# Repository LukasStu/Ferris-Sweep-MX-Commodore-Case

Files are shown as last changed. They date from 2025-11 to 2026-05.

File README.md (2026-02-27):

# Ferris Sweep MX Commodore Case

Custom gasket-mount style case for the Ferris Sweep Bling MX.

## Table of Contents

- [Overview](#overview)
- [Gallery](#gallery)
- [What Changed in v2](#what-changed-in-v2)
- [Repository Structure](#repository-structure)
- [Quick Start](#quick-start)
  - [PART Output Matrix](#part-output-matrix)
- [Architecture Overview](#architecture-overview)
  - [DXF Layer Contract](#dxf-layer-contract)
- [Bill of Materials (BOM)](#bill-of-materials-bom)
- [Print Guidance](#print-guidance)
- [Key Parameters](#key-parameters)
  - [USB Outlet Alignment](#usb-outlet-alignment)
  - [pcb_usb_distance](#pcb_usb_distance)
  - [controller_cover_thickness (optional)](#controller_cover_thickness-optional)
  - [Gasket Setup](#gasket-setup)
  - [Heat Inserts and Screws](#heat-inserts-and-screws)
  - [USB Outlet Cover Retention](#usb-outlet-cover-retention)
- [Acoustics](#acoustics)
- [CI / Automation](#ci--automation)
- [License](#license)

## Overview

The design was inspired by a Reddit post that showed a gasket mount style case for the Ferris Sweep Bling MX. No STL files were published, so this repository contains my own implementation.

Primary focus:

- Protection with an enclosed case
- Access to power switch, reset button, and USB port
- Gasket mount style isolation
- Improved typing acoustics

## Gallery

| | |
|---|---|
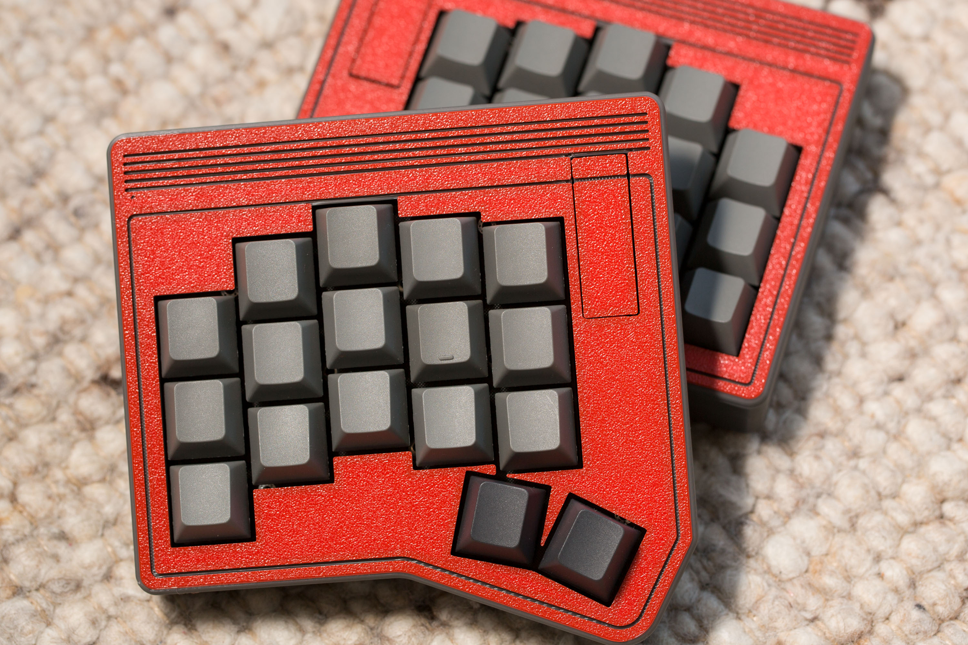
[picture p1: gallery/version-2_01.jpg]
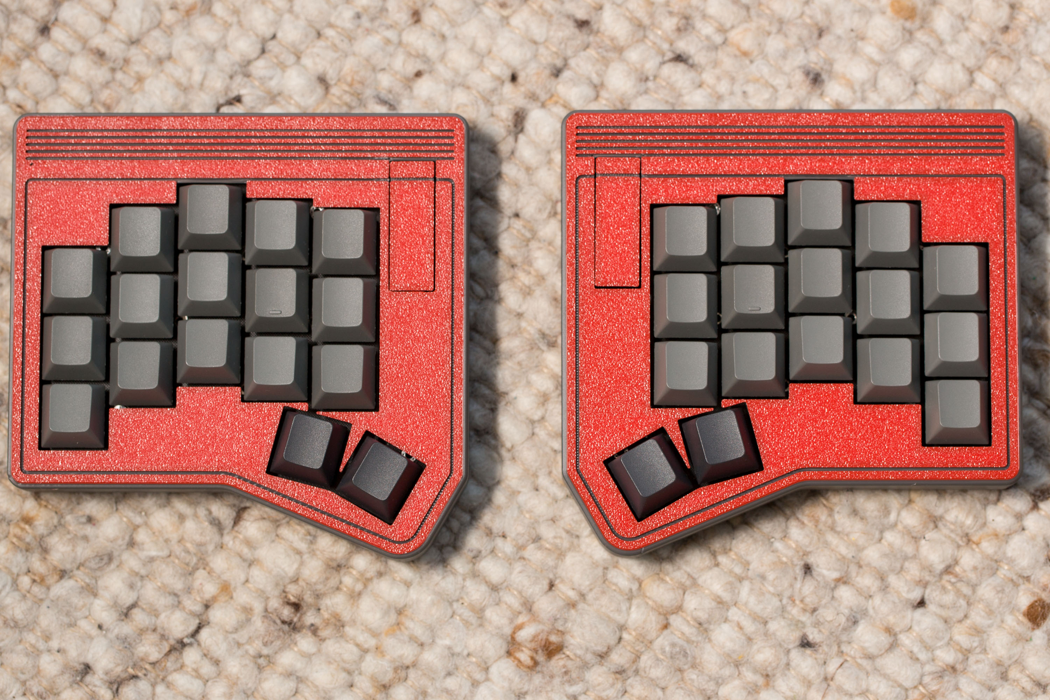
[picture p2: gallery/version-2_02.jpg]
|  |   |
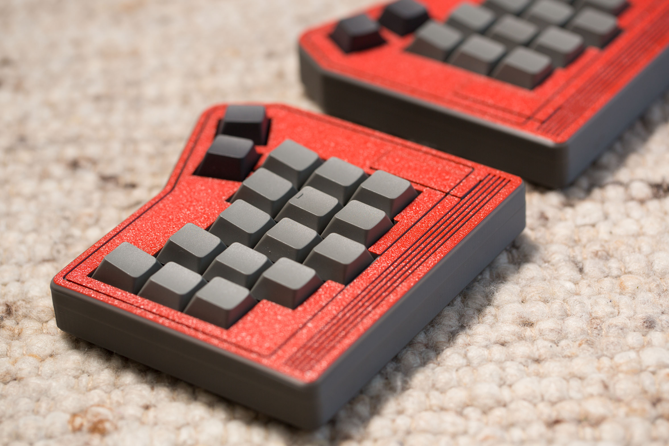
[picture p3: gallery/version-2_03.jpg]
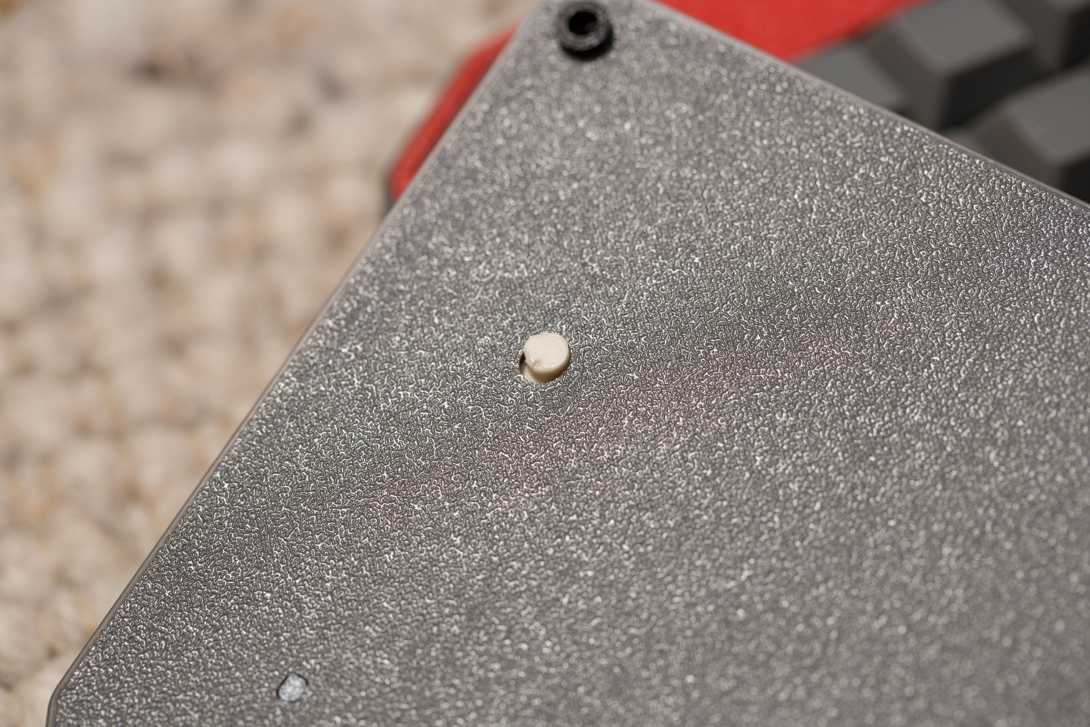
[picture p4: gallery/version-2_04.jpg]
|   |   |
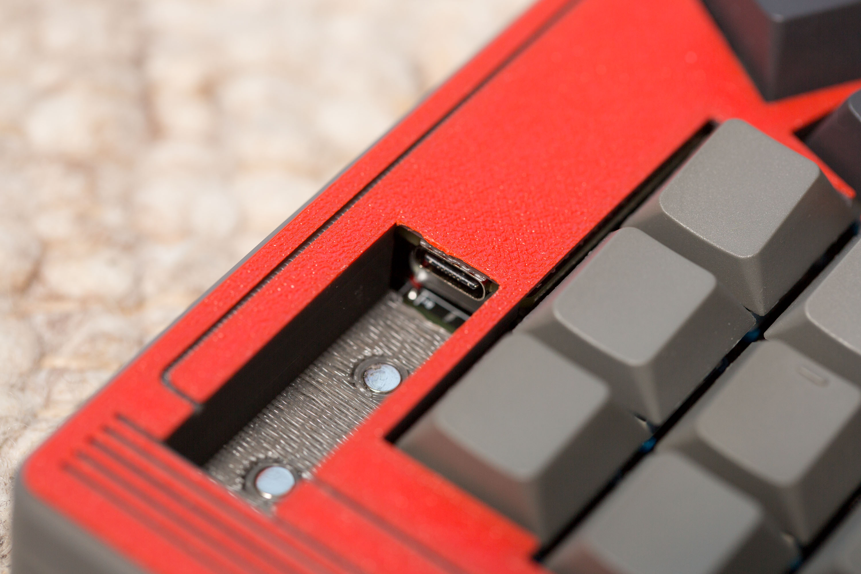
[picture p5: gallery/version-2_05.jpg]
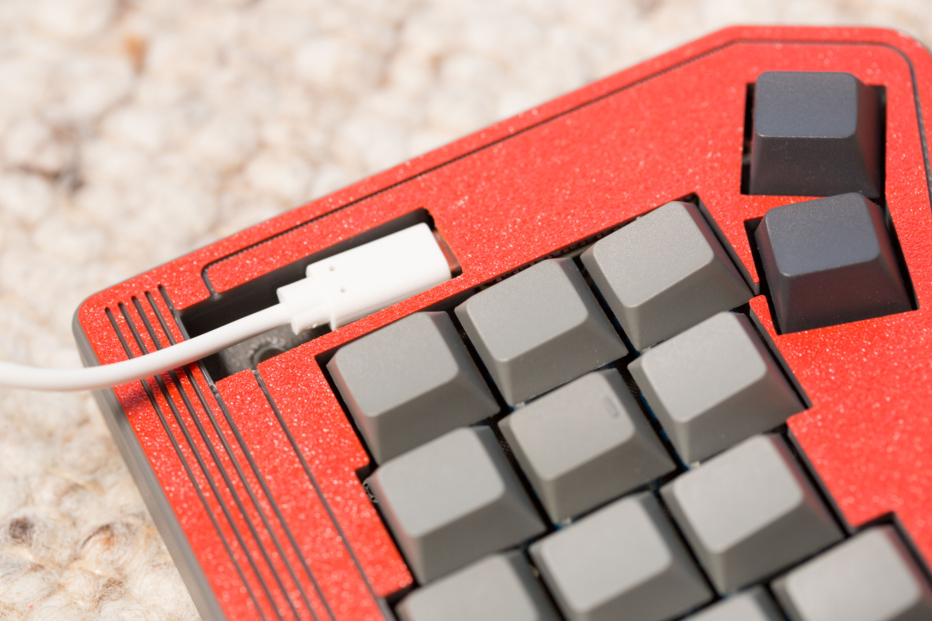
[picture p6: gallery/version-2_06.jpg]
|   |   |
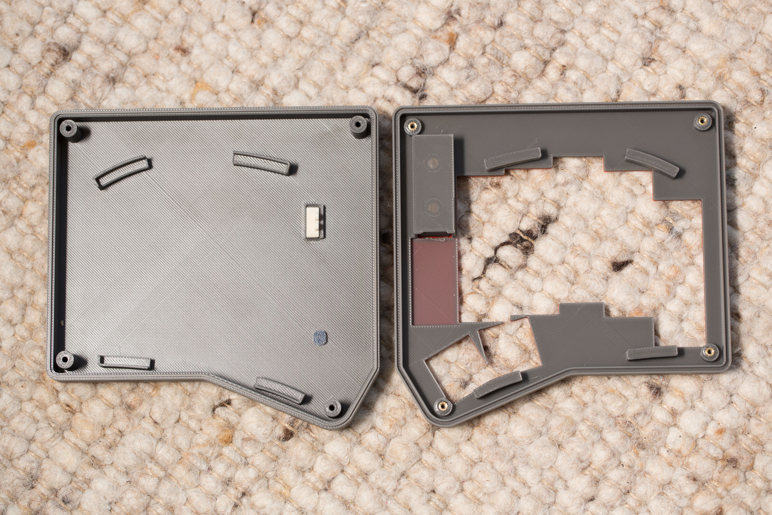
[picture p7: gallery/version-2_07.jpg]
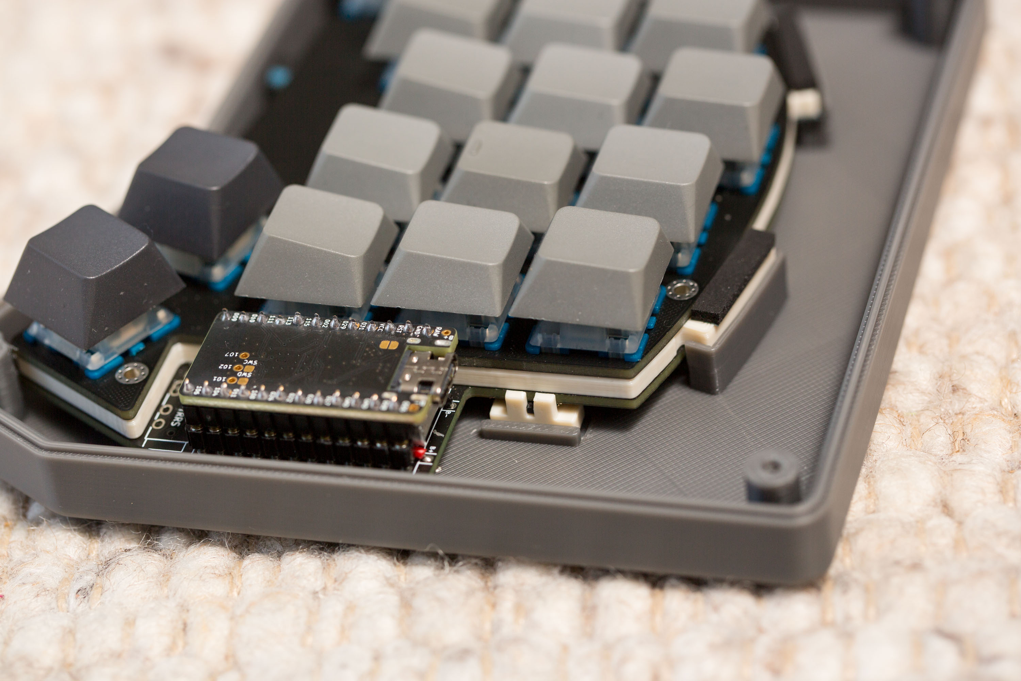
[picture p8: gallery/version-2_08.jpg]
|   |   |

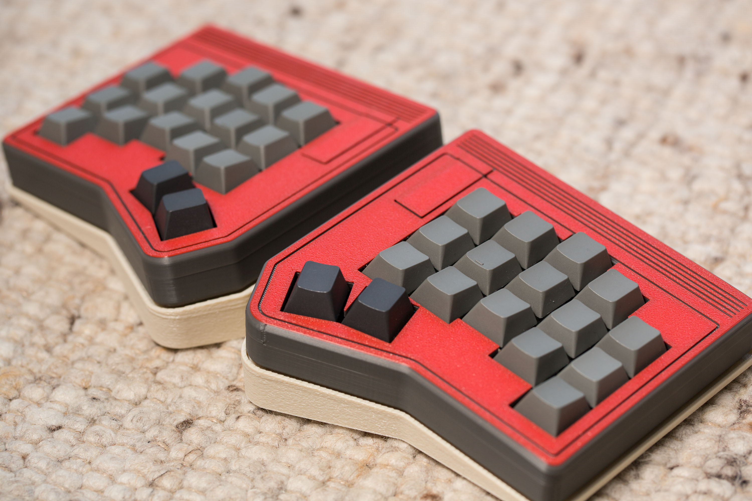
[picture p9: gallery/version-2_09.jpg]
|   | 

## What Changed in v2

- Introduced gasket mount style
- Improved structural rigidity
- Better acoustic behavior

## Repository Structure

- `case/case.scad`: Main OpenSCAD generator
- `case/ferris_sweep_bling_mx.dxf`: Source 2D layers used for all major extrusions
- `gallery/`: Build and fit photos

## Quick Start

1. Open `case/case.scad` in OpenSCAD.
2. Set `PART` to the part you want to export (`top_case`, `bottom_case`, `switch_plate_foam`, etc.).
3. Render with `F6`.
4. Export STL.

Use `PART = "exploded"` to inspect clearances and stack order before final export. You can also set `EXPLODE = 0` to inspect the assembled geometry while still using exploded build logic.

### PART Output Matrix

| `PART` value | STL export | Required for build | Purpose |
|---|---|---|---|
| `top_case` | `top_case.stl` | Yes | Top shell with keycap and controller cutouts |
| `bottom_case` | `bottom_case.stl` | Yes | Bottom shell with supports and screw structures |
| `switch_plate_foam` | `switch_plate_foam.stl` | Yes | Plate/foam interface layer |
| `power_switch_slider` | `power_switch_slider.stl` | Yes | External power slider part |
| `reset_switch_button` | `reset_switch_button.stl` | Yes | External reset button part |
| `usb_plug_cover` | `usb_plug_cover.stl` | Optional | Removable USB outlet cover |
| `rubber_feet` | `rubber_feet.stl` | Optional | Optional printed feet inserts |
| `tent` | `tent.stl` | Optional | Optional tenting support |
| `exploded` | *(view only)* | No | Visual assembly / clearance inspection |

## Architecture Overview

The OpenSCAD code in `case/case.scad` follows a lightweight modular structure:

- `extrude_layer(layer, z, h, delta)` is the primary helper. It imports a DXF layer and extrudes it with optional offset.
- Higher-level modules such as `top_case`, `bottom_case`, and accessories build geometry through boolean operations around shared extrusions.
- `build()` is the entry point. It reads `PART` and renders the selected component.

This separation makes it easy to tune parameters, update DXF layers, or add modules without changing core helper routines.

### DXF Layer Contract

The following DXF layers are expected by `case/case.scad`. Renaming or removing layers will break matching modules.

| Layer name | Purpose |
|---|---|
| `pcb_outline` | PCB and internal clearance envelope |
| `outer_shape` | Main outside perimeter |
| `outer_shape_decor` | Top decorative area cutout |
| `decor_lines` | Decorative line engraving/cutout |
| `keycaps_outline` | Keycap clearance opening |
| `controller_cutout` | Controller/USB area opening |
| `reset` | Reset button geometry |
| `pwr_lid_cutout` | Power slider top cutout |
| `pwr_body` | Power slider body |
| `pwr_circ` | Power slider cap/circle |
| `pwr_body_support` | Internal support under power area |
| `pwr_knob_cutout` | Slider knob relief |
| `pwr_body_overhang` | Slider overhang guidance |
| `pwr_overhang_cutout` | Overhang clearance cutout |
| `pwr_on_label` | Optional ON marking |
| `switches` | Switch opening references |
| `switchplate_outline` | Switchplate foam outline |
| `gasket_supports` | Gasket support contact areas |
| `gasket_supports_rim` | Gasket rim geometry |
| `screw_markers` | Screw/insert marker positions |
| `usb_plug_cutout` | USB cover body cutout |
| `usb_plug_decor` | Optional USB cover decorative cutout |
| `usb_plug_magnets` | USB cover magnet pockets |

## Bill of Materials (BOM)

Quantity notation:

- **Per half** = one keyboard half
- **Total pair** = full split keyboard (two halves)

| Item | Spec used | Per half | Total pair |
|---|---|---|---|
| Heat-set inserts | M2 x 3 x 3.5 | same as screw marker count | 2x per-half count |
| Screws | M2 hex, 4 mm length | same as screw marker count | 2x per-half count |
| USB cover magnets | 4 mm x 1 mm | 2 | 4 |
| Gasket strips | Poron, 2 mm | as required by gasket path | 2x per-half amount |

Notes:

- Heat-set inserts are required for this design.
- Tested insert install temperature in PETG: **190°C**.
- If you use different inserts or screws, adjust the matching parameters in `case/case.scad`.

## Print Guidance

Baseline used for successful builds:

- Material: PETG
- Infill: 40% gyroid
- Supports used: screw hole support areas and the USB cutout region

Recommended starting approach:

- Print each `PART` in its natural flat orientation from OpenSCAD export.
- Supports were used specifically at screw hole support areas and the USB cutout; keep supports targeted to those regions.
- Keep wall/perimeter settings consistent across top and bottom shells for even seam behavior.

## Key Parameters

### USB Outlet Alignment

The position of the USB-C port depends on your solder-pin configuration and controller setup.

#### `pcb_usb_distance`

- Definition: Distance (mm) from PCB surface to USB-C port center
- Purpose: Aligns the USB opening with your connector

<p align="center">
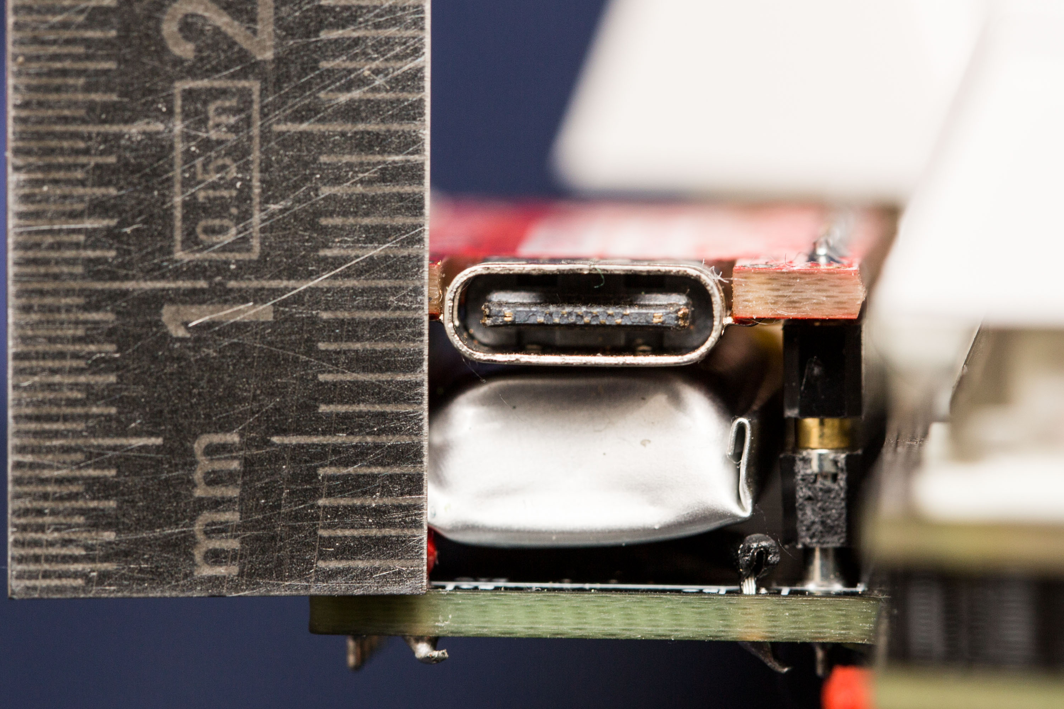
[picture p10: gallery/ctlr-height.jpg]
Measuring PCB to USB-C port center distance
  <br>
  <em>Caption: Measuring PCB-to-USB-C center distance (example value: 9 mm)</em>
</p>

#### `controller_cover_thickness` (optional)

- Definition: Wall thickness above the controller area near the USB outlet
- Default: `1` mm
- Adjustment: Increase if your controller sits deeper or if that wall is too thin

Adjust in `case.scad`:

```scad
pcb_usb_distance = <your measured value>;          // e.g. 9
controller_cover_thickness = <desired thickness>;  // e.g. 1.5
```

Then render (`F6`) and verify alignment before exporting STLs.

### Gasket Setup

The case is designed for Poron gasket strips and uses a compression model.

- Material used: 2 mm Poron foam strips
- Target compression: 60%
- Configured by:

```scad
gasket_thickness = 2;
compression = 0.6;
compressed_gasket_thickness = gasket_thickness * (1 - compression);
```

Adjustable:

- `gasket_thickness`: Match your actual foam thickness
- `compression`: Tune feel and preload

Do not adjust:

- `switch_plate_foam_thickness` should remain fixed. It represents the physical distance between PCB and switch plate defined by the MX switch stack-up.

### Heat Inserts and Screws

Heat-set inserts are required and are installed in the **top shell**.

Reference hardware used for this build:

- Insert: **M2 x 3 x 3.5**
- Screw: **M2 hex, 4 mm thread length**
- Tested insert install temperature in PETG: **190°C**

Install guidance:

- Heat the insert tool, align the insert perpendicular to the hole, and press in slowly.
- Stop when the insert is flush with the pocket surface (avoid over-driving).
- Let the area cool fully before test-fitting screws.

If you use different inserts or screws, tune these parameters in `case/case.scad`:

- `heat_sink_insert_diameter`: Insert outer diameter fit
- `heat_sink_insert_depth`: Insert pocket depth
- `screw_diameter`: Clearance for screw threads
- `head_diameter`: Clearance for screw head
- `thread_length`: Effective screw engagement length
- `thread_intrusion`: How far screw threads extend into the structure
- `screw_support_diameter`: Diameter of local support around screw locations

### USB Outlet Cover Retention

The USB outlet cover is held in place with magnets.

- Magnet size: **4 mm x 1 mm**
- Quantity used: **2 magnets per case half**
- Mounting method used: **glued in place**

## Acoustics

This case is tuned for a muted, less hollow sound profile through gasket isolation and enclosure rigidity.

Baseline used:

- Infill: 40% gyroid
- Gasket: 2 mm Poron strips
- Compression target: 60%

Why this works:

- Gasket isolation reduces direct transfer of high-frequency vibration into the shell
- 40% gyroid infill improves structural consistency and lowers resonance versus low infill
- Enclosed geometry and wall thickness add mass and reduce hollowness

Tuning notes:

- If sound is too sharp: increase `compression` slightly or use softer gasket foam
- If feel is too soft/over-damped: reduce `compression` slightly
- Keep `switch_plate_foam_thickness` unchanged

## CI / Automation

- Build STLs on push: Renders all STL parts on push/PR/manual run and uploads a consolidated `case` artifact
- Build and Release STLs: Runs on tags (`v*`), builds all parts, bundles `case.zip`, and publishes a GitHub Release

## License

See `LICENSE`.

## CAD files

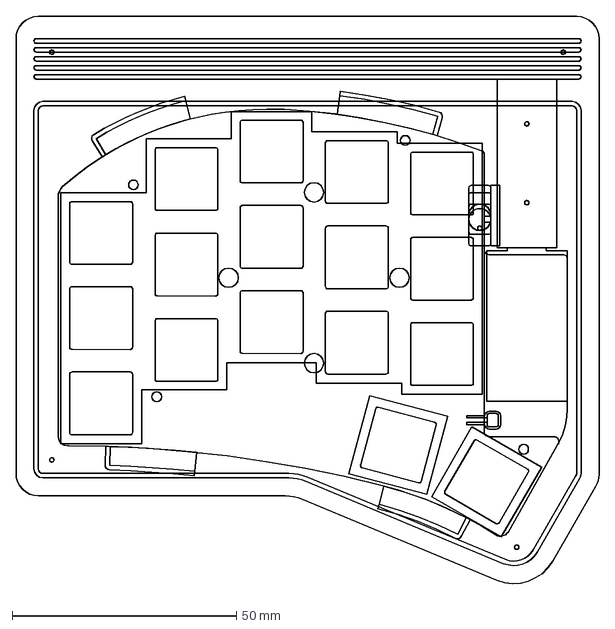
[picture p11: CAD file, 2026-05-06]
case/ferris_sweep_bling_mx.dxf
130.0 x 127.6 mm

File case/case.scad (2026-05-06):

// -----------------------------------------------------------------------------
// Ferris Sweep MX Case Generator
// Author: Lukas Stürmlinger
// Requires: OpenSCAD 2021+ and ferris_sweep_bling_mx.dxf in the same directory.
// Description: Builds top/bottom shells, switch-plate foam, slider, reset button,
//              and optional tent support by extruding DXF layers via extrude_layer().
// Usage: Set PART to "top_case", "bottom_case", etc., then F6 to render.
// Notes: All dimensions in millimeters; DXF layers listed below must be kept in sync.
// CI: Every push triggers .github/workflows/build-stls-on-push.yml to render all STLs via GitHub Actions.
// -----------------------------------------------------------------------------
$fn = 100;

// Dimensions & geometry
// -------------------- Parameters --------------------
// top case
fillet_radius = 2.5;
top_case_thickness = 3;
case_wall_thickness = 3;
controller_cover_thickness = 1;
keycaps_gap = 0.5;
keycaps_cutout_height = 8.5;
decoration_cutout_depth = 1.0;

// bottom case
bottom_thickness = 2;
bottom_gap = 1.5;

// rim
rim = 1;
rim_height = 1;
rim_clear = 0.2;

// PCB + plate
kailh_sockets_thickness = 2;
fr4_thickness = 1.6;
switch_plate_foam_thickness = 3.3;

// gasket
gasket_thickness = 2;
compression = 0.5;
compressed_gasket_thickness = gasket_thickness * (1 - compression);
gasket_rim = 1.5;

// switches
switch_protrusion = 1;
slider_immersion_depth = 0.2;
slider_total_height =
  switch_protrusion + bottom_thickness + bottom_gap + kailh_sockets_thickness + fr4_thickness - 0.5;
MSK_thickness = 1.4;
B3U_thickness = 1.6;

// USB
w_shell = 8.94;
h_shell = 3.26;
r_corner = 1.2;
pcb_usb_distance = 9;
Z_USB = h_shell / 2 + bottom_gap + kailh_sockets_thickness + fr4_thickness + pcb_usb_distance;
usb_main_offset = [ 139.9, -76, Z_USB ];
usb_tunnel_offset = [ 139.9, -28, Z_USB ];
usb_tunnel_len_mm = 50;
usb_plug_thickness = 8;
usb_plug_thickness_clearance = 2;
usb_plug_support_wall_thickness = 1.5;
usb_plug_insert_clearance = 0.5;
magnet_clearance = 0.1;

// Screw positions & sizes
heat_sink_insert_diameter = 2.7;
heat_sink_insert_depth = 3.1;
screw_diameter = 2.5;
thread_length = 4;
head_diameter = 4.5;
thread_intrusion = 2;
screw_support_diameter = 7;
screw_marker_diameter = 1;

// Rubber feet
insert_height = 3;
foot_height = 1.5;
hollow_diameter = head_diameter - 0.9;

// Clearances
clear_pcb_mm = 1.0;
clear_gasket_mm = 0.5;
clear_usb_mm = 0.5;
clear_switch_mm = 0.2;
screw_support_clearance = 0.2;

// Derived Heights
z_bottom_gap = bottom_thickness;
z_kailh_sockets = z_bottom_gap + bottom_gap;
z_pcb = z_kailh_sockets + kailh_sockets_thickness;
z_switchplate_foam = z_pcb + fr4_thickness;
z_switchplate = z_switchplate_foam + switch_plate_foam_thickness;
z_keycaps_cutout = z_switchplate + fr4_thickness;

// bases and tops
z_bottom_case_top = z_keycaps_cutout;
z_top_case_base = z_bottom_case_top;
z_top_case_top = z_bottom_case_top + keycaps_cutout_height;

// Derived
total_height_bottom_case = z_keycaps_cutout;
total_height_top_case = keycaps_cutout_height;

// Single DXF file + layer names
DXF = "ferris_sweep_bling_mx.dxf";

L_pcb_outline = "pcb_outline";
L_outer_shape = "outer_shape";
L_outer_shape_decor = "outer_shape_decor";
L_decor_lines = "decor_lines";
L_keycaps_outline = "keycaps_outline";
L_controller_cutout = "controller_cutout";
L_reset = "reset";
L_reset_cutout = "reset_cutout";
L_pwr_lid_cutout = "pwr_lid_cutout";
L_pwr_body = "pwr_body";
L_pwr_circ = "pwr_circ";
L_pwr_body_support = "pwr_body_support";
L_pwr_knob_cutout = "pwr_knob_cutout";
L_pwr_body_overhang = "pwr_body_overhang";
L_pwr_overhang_cutout = "pwr_overhang_cutout";
L_pwr_on_label = "pwr_on_label";
L_switches = "switches";
L_switchplate_outline = "switchplate_outline";
L_gasket_supports = "gasket_supports";
L_gasket_supports_rim = "gasket_supports_rim";
L_screw_markers = "screw_markers";
L_usb_plug_cutout = "usb_plug_cutout";
L_usb_plug_decor = "usb_plug_decor";
L_usb_plug_magnets = "usb_plug_magnets";

// -----------------------------------------------------------------------------
// ------------------------------- Helpers -------------------------------------
// -----------------------------------------------------------------------------

module extrude_layer(layer, z = 0, h = 1, delta = 0) {
  translate([ 0, 0, z ]) linear_extrude(height = h) offset(delta = delta) import(file = DXF, layer = layer);
}

module screw_hole_layer(z = 0, h = 1, target_diameter = screw_marker_diameter) {
  marker_delta = (target_diameter - screw_marker_diameter) / 2;
  extrude_layer(L_screw_markers, z = z, h = h, delta = marker_delta);
}

// -----------------------------------------------------------------------------
// ------------------------------ Top und bottom basics ------------------------
// -----------------------------------------------------------------------------

module outer_shape_top() {
  difference() {
    union() {
      extrude_layer(L_outer_shape, z = z_top_case_base, h = fillet_radius);
      minkowski() {
        sphere(fillet_radius);
        translate([ 0, 0, z_top_case_base + fillet_radius ])
            extrude_layer(L_outer_shape, h = total_height_top_case - 2 * fillet_radius, delta = -fillet_radius);
      }
    }
    extrude_layer(L_outer_shape, z_top_case_base, h = total_height_top_case - top_case_thickness,
                  delta = -case_wall_thickness);
  }
}

module outer_shape_bottom() {
  difference() {
    union() {
      extrude_layer(L_outer_shape, z = fillet_radius, h = total_height_bottom_case - fillet_radius);
      minkowski() {
        sphere(fillet_radius);
        translate([ 0, 0, fillet_radius ])
            extrude_layer(L_outer_shape, h = total_height_bottom_case - 2 * fillet_radius, delta = -fillet_radius);
      }
    }
    extrude_layer(L_outer_shape, z = z_bottom_gap, h = total_height_bottom_case - bottom_thickness,
                  delta = -case_wall_thickness);
  }
}

module case_rim(delta = 0) {
  difference() {
    extrude_layer(L_outer_shape, z = z_bottom_case_top, h = rim_height + delta,
                  delta = -case_wall_thickness / 2 + rim / 2 + delta / 2);
    extrude_layer(L_outer_shape, z = z_bottom_case_top, h = rim_height + delta,
                  delta = -case_wall_thickness / 2 - rim / 2 - delta / 2);
  }
}

// -----------------------------------------------------------------------------
// ------------------------------ Top und bottom basics ------------------------
// -----------------------------------------------------------------------------

module upper_gasket_taps() {
  difference() {
    extrude_layer(L_gasket_supports, z = z_switchplate + compressed_gasket_thickness,
                  h = fr4_thickness + keycaps_cutout_height - decoration_cutout_depth - compressed_gasket_thickness,
                  delta = 0.2);
    extrude_layer(L_pcb_outline, z = z_switchplate + compressed_gasket_thickness,
                  h = fr4_thickness + keycaps_cutout_height - decoration_cutout_depth - compressed_gasket_thickness,
                  delta = 0.2);
  }
}

module lower_gasket_taps() {
  difference() {
    extrude_layer(L_gasket_supports, z = z_bottom_gap,
                  h = bottom_gap + kailh_sockets_thickness + fr4_thickness - compressed_gasket_thickness);
    extrude_layer(L_pcb_outline, z = z_bottom_gap,
                  h = bottom_gap + kailh_sockets_thickness + fr4_thickness - compressed_gasket_thickness,
                  delta = clear_gasket_mm);
  }
}

module lower_gasket_taps_rims() {
  difference() {
    extrude_layer(L_gasket_supports_rim, z = z_bottom_gap,
                  h = bottom_gap + kailh_sockets_thickness + fr4_thickness + compressed_gasket_thickness + gasket_rim);
    extrude_layer(L_pcb_outline, z = z_bottom_gap,
                  h = bottom_gap + kailh_sockets_thickness + fr4_thickness + compressed_gasket_thickness + gasket_rim,
                  delta = clear_gasket_mm);
  }
}

module keycaps_cutout() {
  extrude_layer(L_keycaps_outline, h = z_top_case_top, delta = 2 * keycaps_gap);
}

module controller_cutout() {
  extrude_layer(L_controller_cutout, h = z_top_case_top - controller_cover_thickness, delta = clear_usb_mm);
}

// -----------------------------------------------------------------------------
// ------------------------------ Buttons, Switches, USB------------------------
// -----------------------------------------------------------------------------

module reset_cutout(delta = 0) {
  extrude_layer(L_reset_cutout, h = bottom_thickness);
}

module reset_lift() {
  extrude_layer(L_reset, z = z_bottom_gap, h = bottom_gap);
}

module reset_switch_button() {
  extrude_layer(L_reset, z = -switch_protrusion, h = bottom_thickness + switch_protrusion);
  extrude_layer(L_reset, z = z_bottom_gap, h = bottom_gap, delta = 1);
}
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

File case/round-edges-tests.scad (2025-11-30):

// ===== USER PARAMETERS =====
total_height = 20;       // Total height INCLUDING bevel
bevel_height = 2;        // Height of beveled top section
bevel_steps = 10;        // Number of steps in bevel
top_offset = -bevel_height;         // Total offset at the top (negative = shrink)
$fn = 20;                // Smoothness for curves
dxf_file = "sweep-bling-mx__bottom-Edge_Cuts.dxf";  // Your DXF shape

// ===== BASE SHAPE =====
module base_shape() {
    import(dxf_file);
}

// ===== MAIN STRAIGHT BODY (below bevel) =====
module straight_body() {
    linear_extrude(height = total_height - bevel_height)
        base_shape();
}

// ===== LINEAR BEVEL MODULE =====
module linear_bevel() {
    for (i = [0 : bevel_steps - 1]) {
        t = i / (bevel_steps - 1);                  // 0 to 1
        offset_amt = t * top_offset;                // interpolate offset
        zpos = i * bevel_height / bevel_steps;      // step Z height

        translate([0, 0, zpos])
            linear_extrude(height = bevel_height / bevel_steps)
                offset(delta = offset_amt)
                    base_shape();
    }
}

// ===== COMBINED FINAL MODEL =====
module beveled_model() {
    union() {
        straight_body();

        // Position bevel on top of body
        translate([0, 0, total_height - bevel_height])
            linear_bevel();
    }
}

// ===== RENDER =====
beveled_model();

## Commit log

2025-11-30 Initial Commodore case version
    [case.scad, ferris_sweep_bling_mx.dxf, round-edges-tests.scad]
2025-12-02 improve tent
    [case.scad]
2025-12-05 remove magic numbers in decor modules
    [case.scad]
2025-12-15 improve decor lines
    [case.scad, ferris_sweep_bling_mx.dxf]
2026-02-23 add gasket mount style
    [case.scad, ferris_sweep_bling_mx.dxf]
2026-02-23 add usb plug opening
    [case.scad, ferris_sweep_bling_mx.dxf]
2026-02-23 add usb plug cover
    [case.scad, ferris_sweep_bling_mx.dxf]
2026-02-23 format code
    [case.scad]
2026-02-23 increase decor depth
    [case.scad]
2026-02-25 improve usb plug opening
    [case.scad, ferris_sweep_bling_mx.dxf]
2026-02-27 polish script
    [case.scad]
2026-02-27 improve rubber feet
    [case.scad]
2026-05-06 reduce gasket compression to 0.2
    [case.scad]
2026-05-06 remove pwr slider cutout and support
    [case.scad]
2026-05-06 add reset_cutout
    [ferris_sweep_bling_mx.dxf]
2026-05-06 fix reset_cutout
    [ferris_sweep_bling_mx.dxf]
2026-05-06 fix reset
    [ferris_sweep_bling_mx.dxf]
2026-05-06 add reset_cutout to case
    [case.scad]
2026-05-06 remove power und reset switches
    [case.scad]
